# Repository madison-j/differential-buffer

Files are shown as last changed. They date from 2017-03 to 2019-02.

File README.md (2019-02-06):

# Quad channel differential buffer board

Set of four differential op-amps (AD8421); 10MHz bandwidth, low noise, variable gain settable with a resistor.

Idea here is to buffer monitor channels at the computer without introducing ground loops.

A set of three boards is available from OSHPark for $95; you can also send the gerbers to be manufactured at your board house of choice!

https://oshpark.com/shared_projects/IT3hNDoY

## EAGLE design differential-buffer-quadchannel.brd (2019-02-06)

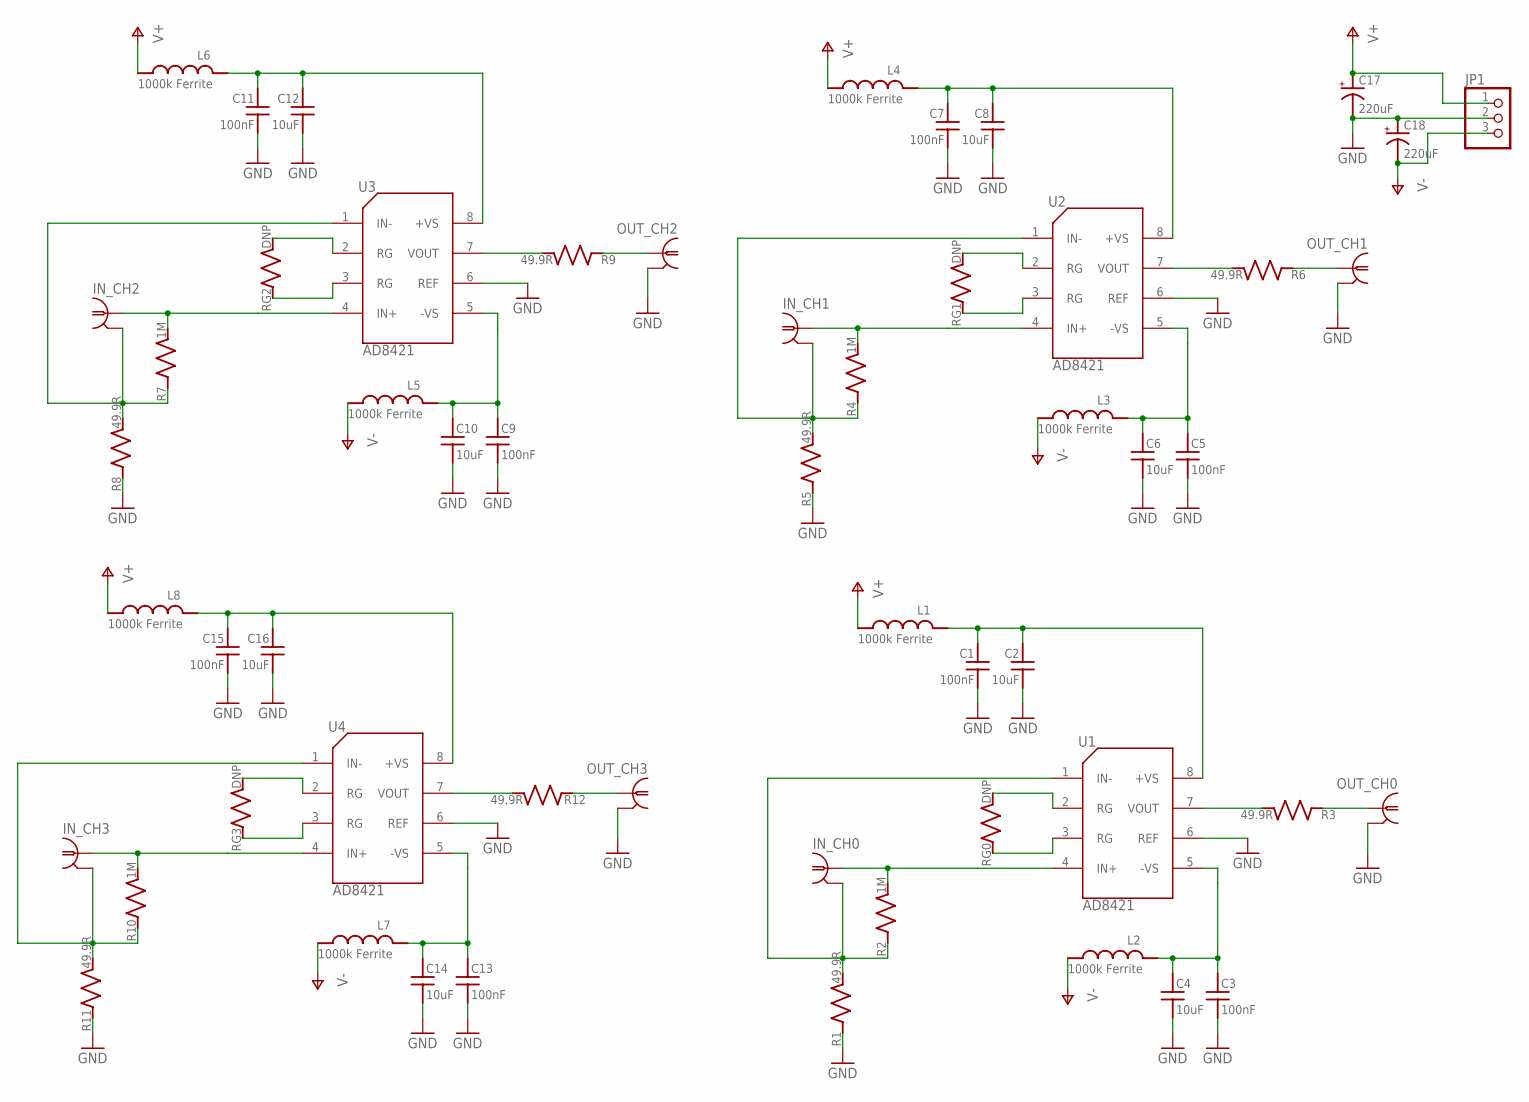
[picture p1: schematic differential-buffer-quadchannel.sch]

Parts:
C1, C3, C5, C7, C9, C11, C13, C15: 100nF; C_MLCC_0603; PARTNO 1276-1936-1-ND
C2, C4, C6, C8, C10, C12, C14, C16: 10uF; C_MLCC_0805; PARTNO 445-14417-1-ND
C17, C18: 220uF; PANASONIC_F; PARTNO PCE3955CT-ND
IN_CH0, IN_CH1, IN_CH2, IN_CH3: BNC-H; BNC90; PARTNO A32260-ND
JP1: PINHD-1X3; 1X03; PARTNO WM4201-ND
L1, L2, L3, L4, L5, L6, L7, L8: 1000k Ferrite; L_FERRITE_0603; PARTNO 445-1548-1-ND
OUT_CH0, OUT_CH1, OUT_CH2, OUT_CH3: BNC-H; BNC90; PARTNO A32260-ND
R1, R3, R5, R6, R8, R9, R11, R12: 49.9R; R_0603; PARTNO P49.9HCT-ND
R2, R4, R7, R10: 1M; R_0603; PARTNO P1.00MHCT-ND
RG0, RG1, RG2, RG3: DNP; R_0402
U1, U2, U3, U4: AD8421; SOIC-8; PARTNO AD8421ARZ-R7CT-ND

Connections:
GND: C1.P$2 (2), C2.P$2 (2), C3.P$2 (2), C4.P$2 (2), C5.P$2 (2), C6.P$2 (2), C7.P$2 (2), C8.P$2 (2), C9.P$2 (2), C10.P$2 (2), C11.P$2 (2), C12.P$2 (2), C13.P$2 (2), C14.P$2 (2), C15.P$2 (2), C16.P$2 (2), C17.-, C18.+, JP1.2, OUT_CH0.2, OUT_CH1.2, OUT_CH2.2, OUT_CH3.2, R1.P$1 (1), R5.P$1 (1), R8.P$1 (1), R11.P$1 (1), U1.6 (REF), U2.6 (REF), U3.6 (REF), U4.6 (REF)
unnamed: OUT_CH0.1, R3.P$1 (1)
unnamed: R3.P$2 (2), U1.7 (VOUT)
unnamed: C1.P$1 (1), C2.P$1 (1), L1.P$1 (1), U1.8 (+VS)
unnamed: RG0.P$1 (1), U1.3 (RG)
unnamed: RG0.P$2 (2), U1.2 (RG)
unnamed: IN_CH1.1, R4.P$2 (2), U2.4 (IN+)
unnamed: IN_CH1.2, R4.P$1 (1), R5.P$2 (2), U2.1 (IN-)
unnamed: OUT_CH1.1, R6.P$1 (1)
unnamed: R6.P$2 (2), U2.7 (VOUT)
unnamed: C5.P$1 (1), C6.P$1 (1), L3.P$1 (1), U2.5 (-VS)
unnamed: C7.P$1 (1), C8.P$1 (1), L4.P$1 (1), U2.8 (+VS)
unnamed: RG1.P$1 (1), U2.3 (RG)
unnamed: RG1.P$2 (2), U2.2 (RG)
unnamed: IN_CH2.1, R7.P$2 (2), U3.4 (IN+)
unnamed: IN_CH2.2, R7.P$1 (1), R8.P$2 (2), U3.1 (IN-)
unnamed: OUT_CH2.1, R9.P$1 (1)
unnamed: R9.P$2 (2), U3.7 (VOUT)
unnamed: C9.P$1 (1), C10.P$1 (1), L5.P$1 (1), U3.5 (-VS)
unnamed: C11.P$1 (1), C12.P$1 (1), L6.P$1 (1), U3.8 (+VS)
unnamed: RG2.P$1 (1), U3.3 (RG)
unnamed: RG2.P$2 (2), U3.2 (RG)
unnamed: IN_CH3.1, R10.P$2 (2), U4.4 (IN+)
unnamed: IN_CH3.2, R10.P$1 (1), R11.P$2 (2), U4.1 (IN-)
unnamed: OUT_CH3.1, R12.P$1 (1)
unnamed: R12.P$2 (2), U4.7 (VOUT)
unnamed: C13.P$1 (1), C14.P$1 (1), L7.P$1 (1), U4.5 (-VS)
unnamed: C15.P$1 (1), C16.P$1 (1), L8.P$1 (1), U4.8 (+VS)
unnamed: RG3.P$1 (1), U4.3 (RG)
unnamed: RG3.P$2 (2), U4.2 (RG)
unnamed: IN_CH0.1, R2.P$2 (2), U1.4 (IN+)
unnamed: IN_CH0.2, R1.P$2 (2), R2.P$1 (1), U1.1 (IN-)
unnamed: C3.P$1 (1), C4.P$1 (1), L2.P$1 (1), U1.5 (-VS)
V+: C17.+, JP1.1, L1.P$2 (2), L4.P$2 (2), L6.P$2 (2), L8.P$2 (2)
V-: C18.-, JP1.3, L2.P$2 (2), L3.P$2 (2), L5.P$2 (2), L7.P$2 (2)

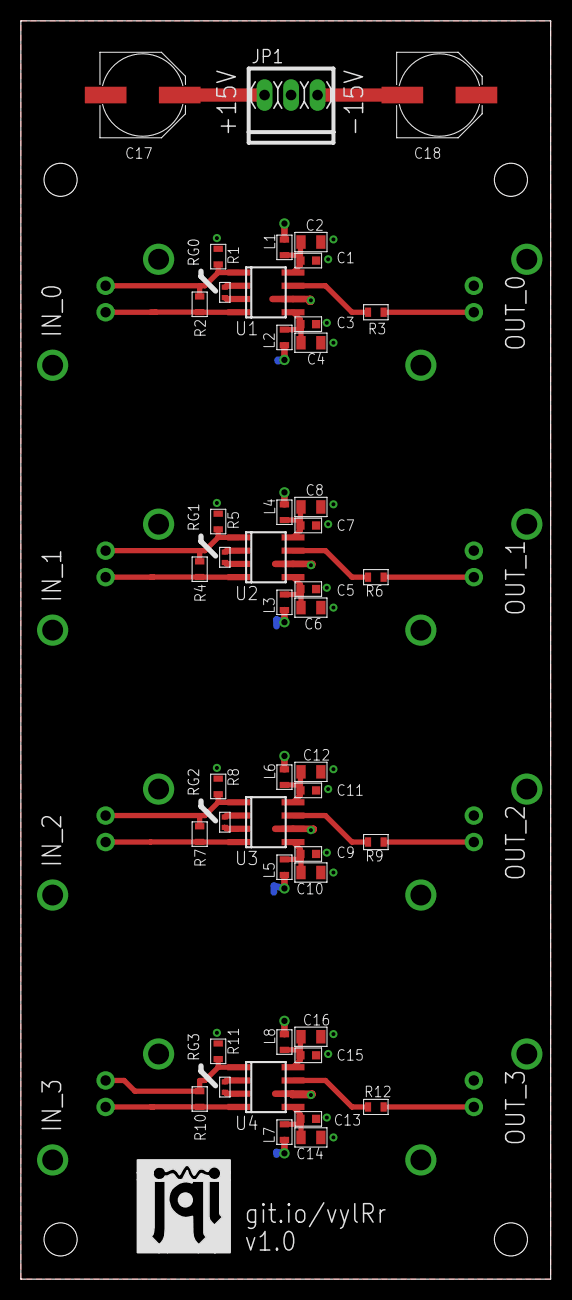
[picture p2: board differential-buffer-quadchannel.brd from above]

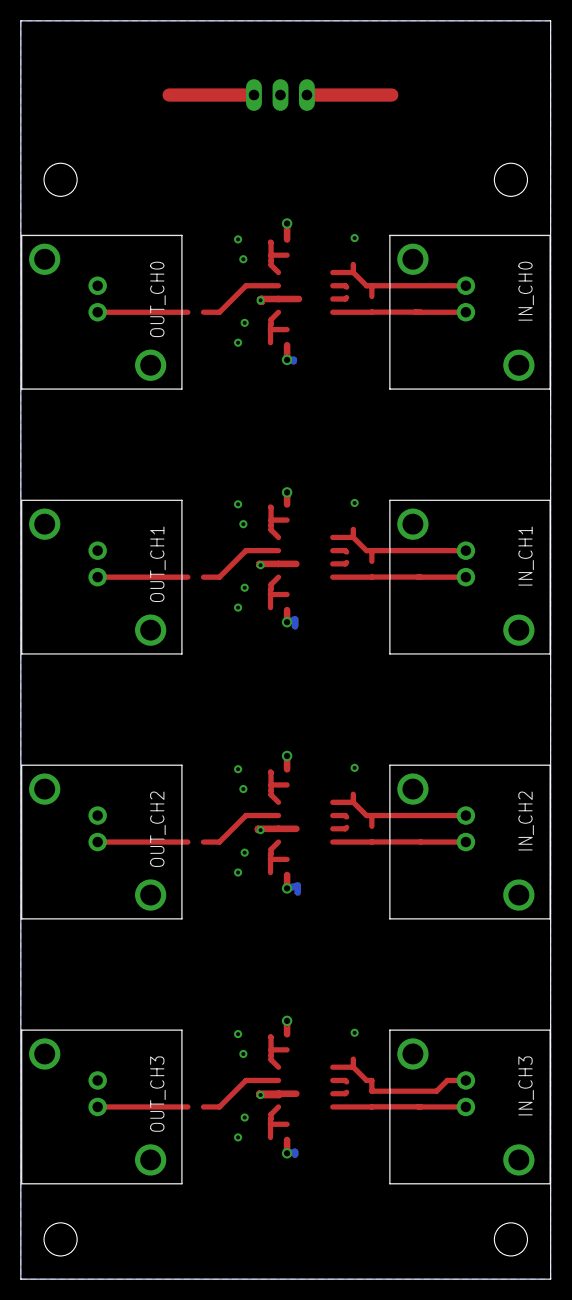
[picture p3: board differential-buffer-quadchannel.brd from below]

Board: 4 copper layers, 50.8 x 120.7 mm, 56 parts (8 on the bottom side), 35 nets.

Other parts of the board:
U$1: JQI_LOGO_NEGATIVE-SILKSCREEN

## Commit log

2017-03-05 Added part numbers
    [differential-buffer-quadchannel.brd, differential-buffer-quadchannel.sch]
2019-02-06 changed RA BNC to vertical
    [differential-buffer-quadchannel.brd]
